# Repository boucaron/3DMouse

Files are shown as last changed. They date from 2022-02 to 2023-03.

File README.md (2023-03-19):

# 3DMouse
## Status
This is still in prototyping phase.... not a polished product by any means, nerd only, but working !
 - Basic Rough Hardware [OK]
 - Firmware [OK]
 - Software for Control and Customization [Control OK, Customization PENDING, Speech Recognition PENDING]

## Overview
Inspired by the great work made by https://github.com/FaqT0tum/Orbion_Space_Mouse
- Using exactly the same hardware but without the LCD Display Part. 
- Cost less than 20$ 
- The idea is to have a small software on the PC where you can "**program**" the firmware of the 3D Mouse according to your software and your preferences, hence the removal of the LCD screen
- Easy to prototype 

## BOM
 - Arduino Pro Micro (**ATMEL32U4**) + Soldered prototyping pins + Associated USB Cable
 - Encoder (**KY-040**)
 - Joystick (**KY-023**)
 - 6 M3 Screw 6mm length
 - Few prototyping female-female cables 

## CAD/3D Printed Parts
- It is a test bed: a base to integrate the Joystick + Arduino, a custom button on top of the Encoder and a custom Encoder/Joystick base.
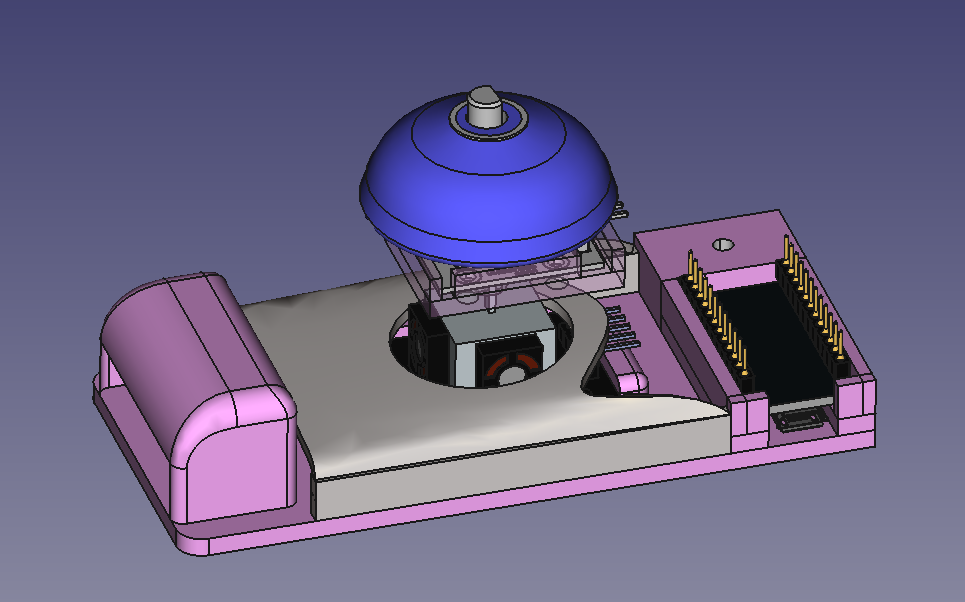
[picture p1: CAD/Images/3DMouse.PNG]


### 3D Printing Steps
- The tolerances for the holes are fully customizable inside the provided FreeCAD files, each printer/filament is different. Try to use the same filament roll when 3D printing those parts to prevent additional iterations due to tolerance changes.

1) Start by first printing the custom Encoder/Joystick base (less than 1 hour in 0.2mm) to setup your baseline for Tolerances for the M3 holes and the **critical tolerance** to the Joystick pin (not too tight, but no play). Orientation is upside down to finish the Joystick pin hole: you will have few supports to remove. Then update accordingly the FreeCAD/STL file for the tolerance.

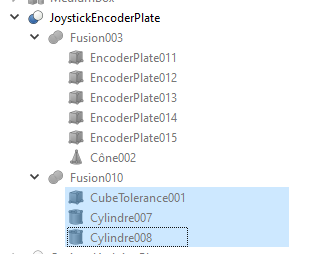
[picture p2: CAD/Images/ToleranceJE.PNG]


2) For the Encoder button you will have to perform the same step for the tolerance (a bit more than 1 hour to print in 0.2mm).

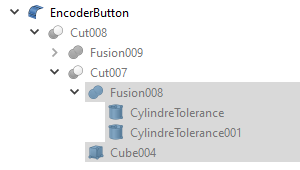
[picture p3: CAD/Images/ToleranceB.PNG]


3) Finally the base using the tolerance for M3 holes you put in the first step.

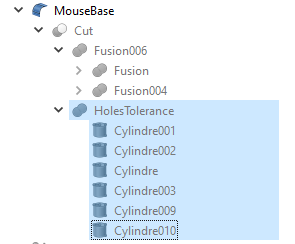
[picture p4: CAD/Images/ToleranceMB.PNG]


## Assembly
1) Put on the 3D Printed Base the Joystick and screw 4 M3 by 6mm on it
2) Put the Encoder on the 3D Printed Joystick/Encoder Plate and screw 2 M3 by 6MM on it
3) Put the 3D Printed Button on the Encoder 
4) Push the 3D Printed Joystick/Encoder Plate on the Joystick pin
5) Put the Arduino in the base as shown in the previous image
6) Put the wires (TODO: schematic)
7) Compile and Upload the firmware

## Firmware 
- Regular Arduino Env using standard libraries + Encoder library (provided in Arduino IDE): compile and upload
- *PoC*: basic features are there, may still change slightly from a commit to another one
- High-Level:
    -   Basic Loop: 
        -  Read Serial Port (if something present to change the configuration/the mode of the mouse)
        -  Read 3D Mouse Inputs (Buttons, Encoder, Joystick)
        -  Process and write to the PC through USB HID (Keyboard/Mouse)
    -   Features:
        - Debug Hardware (serial monitor) [OK]
        -  Basic Mouse Emulator (single button) [OK]
        -  **FreeCAD** (translate, rotation mode) [OK] [Experimental: Click on Joystick Button switch back and forth from Translate/Rotate mode]
        -  **Blender** (translate, rotation mode) [OK]
        -  **ChopChop3D Slicer** (translate, rotation mode) [OK]
        -  **Fusion360** (translate, rotation mode) [OK]	
        -  **3D Builder** (translate, rotation mode) [OK]
        -  **Painter 3D** (translate, rotation mode) [OK]
        -  **OpenSCAD** (translate, rotation mode) [OK]
        -  ZBrush (translate, rotation, scale mode) [TO TEST]
    -   How to:
        -  Connect the 3DMouse to the Computer
        -  Arduino IDE: Compile and Upload the Firmware
        -  Arduino IDE: Launch the Serial Monitor
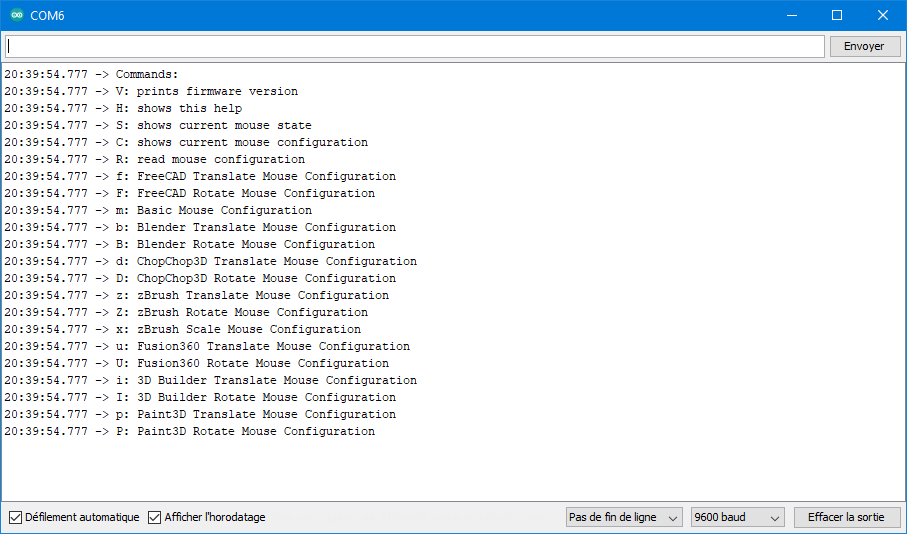
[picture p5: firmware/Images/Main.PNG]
	
        -  Connect with 9600 baud, No End of Line
        -  Type H and Send
        -  Then choose the mode you need: Type the character and Send

## Software
- *PoC*: basic features are there, may change a bit from a commit to another one
    -   Connect to the Mouse [OK]
    -   Serial Port Monitor [OK]
    -   Update the Mode of the Mouse on the Fly with Buttons [OK]
    -   Customization for Mouse Configuration [PENDING] --> Actually there are several modes already implemented, you can easily add yours
    -   Speech Recognition (using Whisper) + Speech Synthesis [WORK IN PROGRESS]
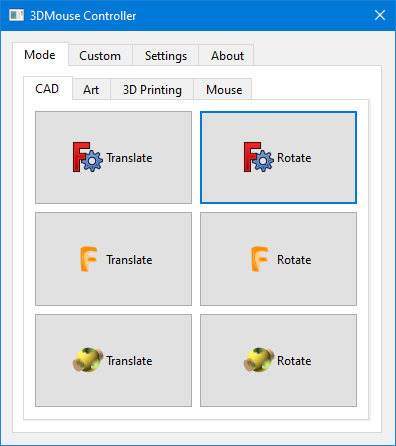
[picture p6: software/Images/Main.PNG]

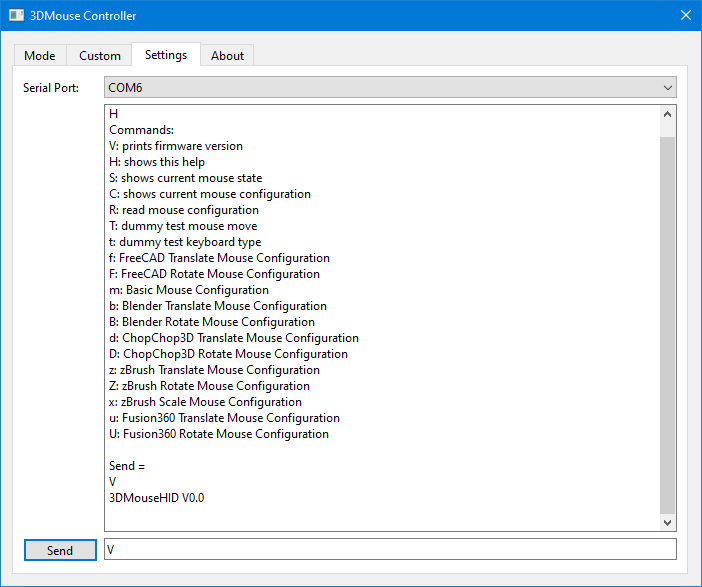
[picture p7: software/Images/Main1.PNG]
	
    
# License
**MIT** see LICENSE file.

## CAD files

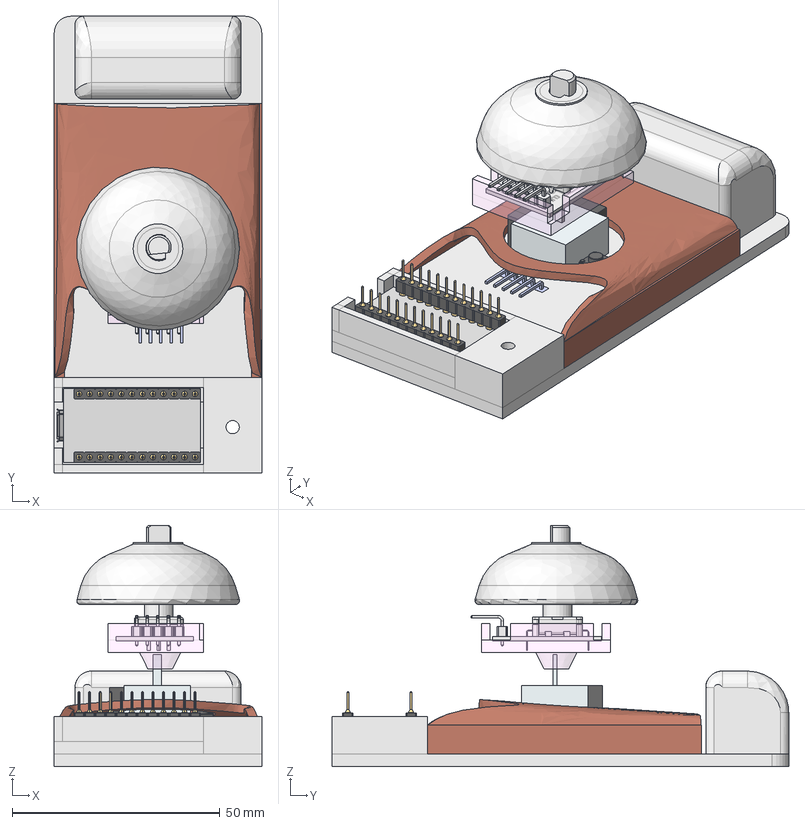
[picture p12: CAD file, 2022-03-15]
CAD/3DMouse_CoverJoystick.FCStd
50.0 x 110.0 x 58.1 mm
Rotary Encoder
Rotary Encoder001
Rotary Encoder002
Rotary Encoder003
D-handle
pcb
2.54 5PIN 90
2.54 5PIN 091
2.54 5PIN 092
2.54 5PIN 093
2.54 5PIN 094
2.54 5PIN 095
2.54 5PIN 096
2.54 5PIN 097
2.54 5PIN 098
2.54 5PIN 099
board001
potentiometer___010
potentiometer___011
potentiometer___012
potentiometer___013
potentiometer___015
potentiometer___016
potentiometer___017
potentiometer___018
tactileswitch-short001
micro board
MICRO_stackable header 12
MICRO_stackable header pin
MICRO_stackable header pin001
MICRO_stackable header pin002
MICRO_stackable header pin003
MICRO_stackable header pin004
MICRO_stackable header pin005
MICRO_stackable header pin006
MICRO_stackable header pin007
MICRO_stackable header pin008
MICRO_stackable header pin009
MICRO_stackable header pin010
MICRO_stackable header pin011
micro usb shell
micro usb internal
micro usb contact
micro usb contact001
micro usb contact002
micro usb contact003
micro usb contact004
atmega32U4
MICRO_cap106C
MICRO_cap106C001
MICRO_stackable header 014
MICRO_stackable header pin012
MICRO_stackable header pin013
MICRO_stackable header pin014
MICRO_stackable header pin015
MICRO_stackable header pin016
MICRO_stackable header pin017
MICRO_stackable header pin018
MICRO_stackable header pin019
MICRO_stackable header pin020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

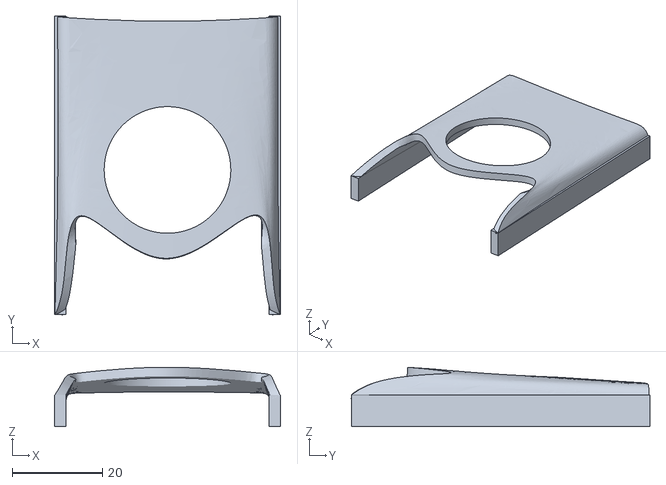
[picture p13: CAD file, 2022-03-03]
STL/CoverJoystick.stl
50.0 x 66.1 x 13.1

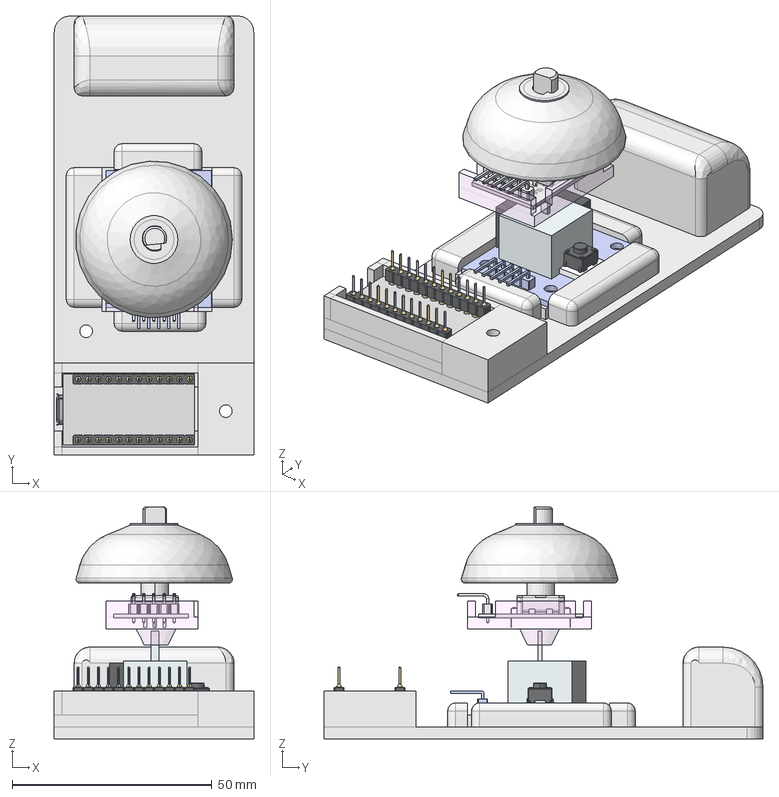
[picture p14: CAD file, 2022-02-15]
CAD/3DMouse.FCStd
50.0 x 110.0 x 58.1 mm
Rotary Encoder
Rotary Encoder001
Rotary Encoder002
Rotary Encoder003
D-handle
pcb
2.54 5PIN 90
2.54 5PIN 091
2.54 5PIN 092
2.54 5PIN 093
2.54 5PIN 094
2.54 5PIN 095
2.54 5PIN 096
2.54 5PIN 097
2.54 5PIN 098
2.54 5PIN 099
board
potentiometer___
potentiometer___001
potentiometer___002
potentiometer___003
potentiometer___005
potentiometer___006
potentiometer___007
potentiometer___008
tactileswitch-short
micro board
MICRO_stackable header 12
MICRO_stackable header pin
MICRO_stackable header pin001
MICRO_stackable header pin002
MICRO_stackable header pin003
MICRO_stackable header pin004
MICRO_stackable header pin005
MICRO_stackable header pin006
MICRO_stackable header pin007
MICRO_stackable header pin008
MICRO_stackable header pin009
MICRO_stackable header pin010
MICRO_stackable header pin011
micro usb shell
micro usb internal
micro usb contact
micro usb contact001
micro usb contact002
micro usb contact003
micro usb contact004
atmega32U4
MICRO_cap106C
MICRO_cap106C001
MICRO_stackable header 014
MICRO_stackable header pin012
MICRO_stackable header pin013
MICRO_stackable header pin014
MICRO_stackable header pin015
MICRO_stackable header pin016
MICRO_stackable header pin017
MICRO_stackable header pin018
MICRO_stackable header pin019
MICRO_stackable header pin020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

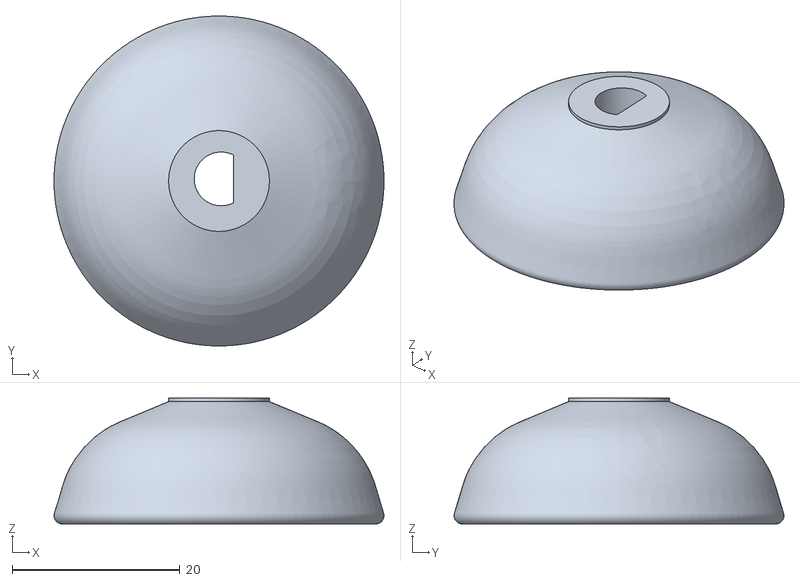
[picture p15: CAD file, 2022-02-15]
STL/EncoderButton.stl
39.3 x 39.3 x 15.0

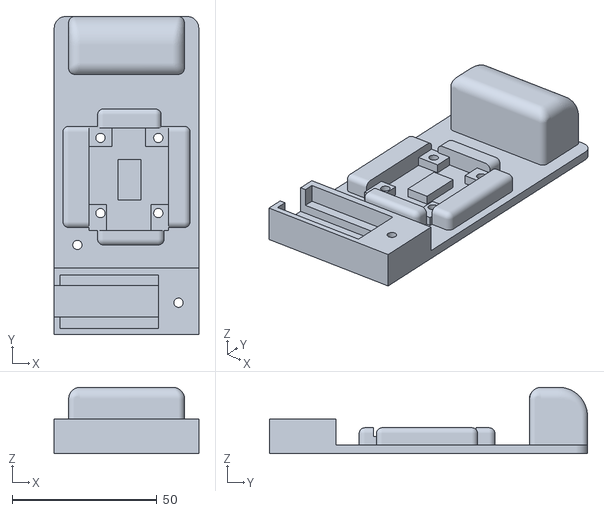
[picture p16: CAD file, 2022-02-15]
STL/MouseBase.stl
50.0 x 110.0 x 23.0

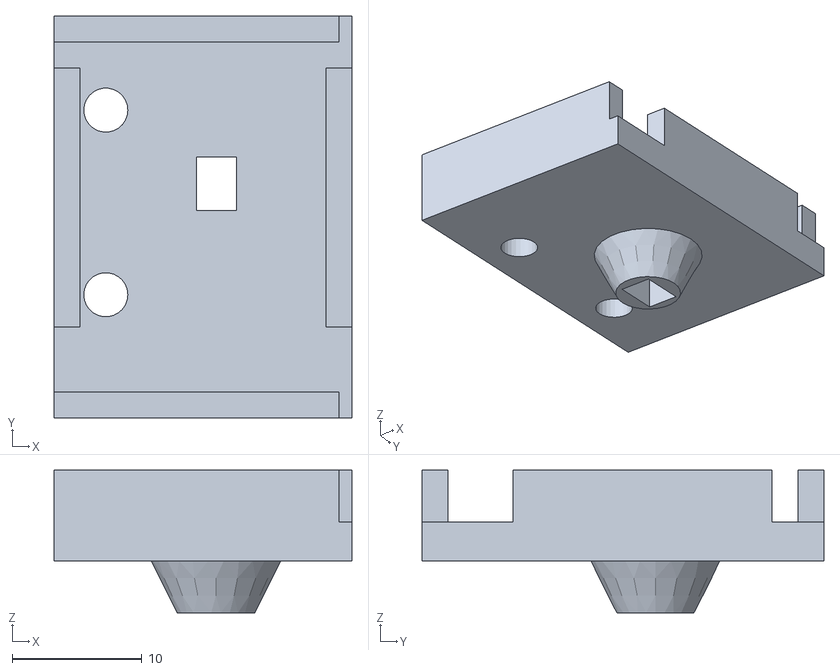
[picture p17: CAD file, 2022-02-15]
STL/JoystickEncodePlate.stl
23.0 x 31.0 x 11.0

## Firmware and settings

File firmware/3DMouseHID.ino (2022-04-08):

// (c) 2022 Julien BOUCARON under MIT License


// Standard Arduino Lib
#include "Keyboard.h"
#include "Mouse.h"

#ifdef JB3DMOUSE_USE_ENCODER
#include "Encoder.h" // https://github.com/PaulStoffregen
#endif

#define SERIALBUFLEN 40
#define MOUSEBUFLEN 20

const char *MVERSION = "3DMouseHID V0.1";

const int pinLed = LED_BUILTIN;

// JOYSTICK
const int horzPin = A1;         // Pin Analog output of X
const int vertPin = A2;        // Pin Analog output of Y
const int joyButt = 15;         // Pin Joystick Button

#ifdef JB3DMOUSE_USE_ENCODER
// ENCODER
const int encBut = 5;    //Pin encoder Button
const int encDT = 7;       // Pin  Detect
const int encCLK = 6;      // Pin  Clockwise
Encoder myEnc(encDT, encCLK);
long positionEnc  = -999;
#endif


void freecadConfiguration(bool);
void basicMouseConfiguration();
void blenderConfiguration(bool);
void chopchop3DConfiguration(bool);
void zBrushConfiguration(int);
void fusion360Configuration(bool);
void M3DBuilderConfiguration(bool);
void Paint3DConfiguration(bool);
void OpenSCADConfiguration(bool);




struct  MouseState {
  byte UpX, DownX;
  byte UpY, DownY;
  byte UpZ, DownZ;
  byte ButtonZ;
  int RotateZ;


  int YZero, XZero;
  int offsetJoyX, offsetJoyY;
  int XValue, YValue;
  int XSens, YSens;

 


  // Move performed before releasing
//   int x,y;

  void reset() {
    UpX = 0 ; DownX = 0;
    UpY = 0 ; DownY = 0;
    UpZ = 0 ; DownZ = 0;
    ButtonZ = 0 ;
    RotateZ = 0;
    XSens = 0; YSens = 0;

   
    offsetJoyX = 5;    // set this value if the joystick moves by itself : 15
    offsetJoyY = 5;    // set this value if the joystick moves by itself : 15


  }

  void setup() {
    reset();
    YZero = 0; XZero = 0;
    YZero = analogRead(vertPin);
    XZero = analogRead(horzPin);
   
 /*   x = 0;
    y = 0; */
  }


  void print() {
    Serial.println(F("State:"));
    Serial.print(F("UpX:")); Serial.print(UpX); Serial.println();
    Serial.print(F("DownX:")); Serial.print(DownX); Serial.println();
    Serial.print(F("UpY:")); Serial.print(UpY); Serial.println();
    Serial.print(F("DownY:")); Serial.print(DownY); Serial.println();
    Serial.print(F("UpZ:")); Serial.print(UpZ); Serial.println();
    Serial.print(F("DownZ:")); Serial.print(DownZ); Serial.println();
    Serial.print(F("ButtonZ:")); Serial.print(ButtonZ); Serial.println();
    Serial.print(F("RotateZ:")); Serial.print(RotateZ); Serial.println();
    Serial.print(F("XZero:")); Serial.print(XZero); Serial.println();
    Serial.print(F("YZero:")); Serial.print(YZero); Serial.println();    
    Serial.print(F("OffsetJoyX")); Serial.print(offsetJoyX); Serial.println();
    Serial.print(F("OffsetJoyY")); Serial.print(offsetJoyY); Serial.println();
    Serial.print(F("XValue:")); Serial.print(XValue); Serial.println();
    Serial.print(F("YValue:")); Serial.print(YValue); Serial.println();
    Serial.print(F("XSens:")); Serial.print(XSens); Serial.println();
    Serial.print(F("YSens:")); Serial.print(YSens); Serial.println();
  }



};



enum MouseKeyHIDMode {
  NOTSET,
  KEYBOARD_PRESS,
  KEYBOARD_RELEASE,
  MOUSE_PRESS,
  MOUSE_RELEASE
};

struct MouseHIDData {
  uint8_t mouseButton;
  int8_t xAxis, yAxis, wheel;
  void (*callback) ();
};

struct KeyHIDData {
  uint8_t keyboardCode;
  void (*callback) ();
};

union HIDData {
  MouseHIDData mouse;
  KeyHIDData keyboard;
};


/** Sent message */
struct MouseKeyHID {
  MouseKeyHIDMode mode;
  HIDData data;
  


  void print() {
    Serial.print("<<");
    switch (mode) {
       case NOTSET: Serial.print(F("NOTSET")); break;
       case KEYBOARD_PRESS: Serial.print(F("KEYBOARD_PRESS")); break;
       case KEYBOARD_RELEASE: Serial.print(F("KEYBOARD_RELEASE")); break;
       case MOUSE_PRESS: Serial.print(F("MOUSE_PRESS")); break;
       case MOUSE_RELEASE: Serial.print(F("MOUSE_RELEASE")); break;
       default: Serial.print(F("Unknown mode!")); break;
    }
    Serial.print(F(":"));
    if ( mode == KEYBOARD_PRESS || mode == KEYBOARD_RELEASE ) {
      Serial.print(data.keyboard.keyboardCode); Serial.print(":");     
    }
    else if ( mode == MOUSE_PRESS || mode == MOUSE_RELEASE ) {
     Serial.print(data.mouse.mouseButton); Serial.print(F(":"));
     Serial.print(data.mouse.xAxis); Serial.print(F(":"));
     Serial.print(data.mouse.yAxis); Serial.print(F(":"));
     Serial.print(data.mouse.wheel);  Serial.print(F(":"));
    }
    Serial.println(F(">>"));
  }

  void read() {
    int mmode = Serial.parseInt();
    switch ( mmode ) {
      case 0: mode = NOTSET; break;
      case 1: mode = KEYBOARD_PRESS; break;
      case 2: mode = KEYBOARD_RELEASE; break;
      case 3: mode = MOUSE_PRESS; break;
      case 4: mode = MOUSE_RELEASE; break;
      default: Serial.print(F("Unknown mode!")); break;
  }
    if ( mode == KEYBOARD_PRESS || mode == KEYBOARD_RELEASE ) {
      data.keyboard.keyboardCode = Serial.parseInt();
    } else if ( mode == MOUSE_PRESS || mode == MOUSE_RELEASE ) {
      data.mouse.mouseButton = Serial.parseInt();
      data.mouse.xAxis = Serial.parseInt();
      data.mouse.yAxis = Serial.parseInt();
      data.mouse.wheel = Serial.parseInt();
    }    
  }

  void writeHID(byte up, int XSens, int YSens, MouseState &mouseState) {
    
    if ( up != 0 ) {
      switch ( mode ) {       
        case KEYBOARD_PRESS:
          Keyboard.press(data.keyboard.keyboardCode); 
              // DEBUG
             // Serial.println("Keyboard press");   
             if ( data.keyboard.callback != NULL ) { data.keyboard.callback(); }
          break;
        case KEYBOARD_RELEASE:
          Keyboard.release(data.keyboard.keyboardCode); 
          // DEBUG
          // Serial.println("Keyboard release");
          if ( data.keyboard.callback != NULL ) { data.keyboard.callback(); }   
          break;
        case MOUSE_PRESS: 
          if ( data.mouse.mouseButton != 0 ) {
              Mouse.press(data.mouse.mouseButton);  
              // DEBUG
              // Serial.println("Mouse press");            
          }                
          Mouse.move(data.mouse.xAxis * XSens, data.mouse.yAxis * YSens, data.mouse.wheel);
           
          // DEBUG
          //Serial.print("Mouse move = X  "); Serial.println(data.mouse.xAxis * XSens);
          // Serial.print("Mouse move = Y  "); Serial.println(data.mouse.yAxis * YSens);
          // mouseState.x += data.mouse.xAxis * XSens;
          // mouseState.y += data.mouse.yAxis * YSens;
          // Serial.println( mouseState.x);

          if ( data.mouse.callback != NULL ) { data.mouse.callback(); }
          break;
        case MOUSE_RELEASE:
          if ( data.mouse.mouseButton != 0 ) {
            Mouse.release(data.mouse.mouseButton);
            // DEBUG
            // Serial.println("Mouse release");     
          }          
          Mouse.move(data.mouse.xAxis * XSens, data.mouse.yAxis * YSens, data.mouse.wheel);                   
          // DEBUG
          // Serial.println("Mouse move = X "); Serial.print(data.mouse.xAxis * XSens);
          // Serial.println("Mouse move = Y  "); Serial.print(data.mouse.yAxis * YSens);
          // mouseState.x += data.mouse.xAxis * XSens;
          // mouseState.y += data.mouse.yAxis * YSens;
          if ( data.mouse.callback != NULL ) { data.mouse.callback(); }
          break;
      }
     
    }
  }

  void reset() {
    mode = NOTSET;
  }

  void cleanData() {
    switch(mode) {
      case KEYBOARD_PRESS:                  
      case KEYBOARD_RELEASE:       
          data.keyboard.keyboardCode = 0;
          data.keyboard.callback = NULL;
         break;
      case MOUSE_PRESS:  
      case MOUSE_RELEASE:
          data.mouse.mouseButton = 0;
          data.mouse.xAxis = 0;
          data.mouse.yAxis = 0;
          data.mouse.wheel = 0;
          data.mouse.callback = NULL;
         break;
    }
  }



};



// STATIC BUFFER CONTAININGALL THE CONF
MouseKeyHID mouseBuf[MOUSEBUFLEN];

/**
 * List of moves to be performed on each "key" in sequence
 */
struct MouseKeyConf { 
  int from; // Index in mouseBuf for the move
  int to; // Index in mouseBuf for the move
  
  void reset() { 
    from = -1;
    to  = -1;
  }

  void print() {
    Serial.println(to-from); Serial.println(" moves");
    for(int i = from ; i < to ; i++ ) {      
      mouseBuf[i].print();
    }
  }

  void read() {
    from = Serial.parseInt();
    to = Serial.parseInt();
    for(int i = from ; i < to ; i++ ) {
      mouseBuf[i].read();
    }
  }

  void writeHID(byte up, int XSens, int YSens, MouseState &mouseState) {
    if ( from == -1 || to == -1 ) {
      return;
    } else {
      for(int i = from ; i < to ; i++ ) {
        mouseBuf[i].writeHID(up, XSens, YSens, mouseState);
      }
    }
  }
};


struct MouseConf {
  MouseKeyConf UpX, DownX;
  MouseKeyConf UpY, DownY;
  MouseKeyConf UpZ, DownZ;

  MouseKeyConf ButtonZ;
  MouseKeyConf RotateZ;

// Run before and after performing any "moves"
  MouseKeyConf before, after;

  void reset() {
    UpX.reset(); DownX.reset();
    UpY.reset(); DownY.reset();
    UpZ.reset(); DownZ.reset();

    ButtonZ.reset();
    RotateZ.reset();

  }

  void print() {
    Serial.println(F("Configuration:"));
    Serial.print(F("UpX:")); UpX.print();  Serial.println();
    Serial.print(F("DownX:")); DownX.print(); Serial.println();
    Serial.print(F("UpY:")); UpY.print();  Serial.println();
    Serial.print(F("DownY:")); DownY.print(); Serial.println();
    Serial.print(F("UpZ:")); UpZ.print(); Serial.println();
    Serial.print(F("DownZ:")); DownZ.print(); Serial.println();
    Serial.print(F("ButtonZ:")); ButtonZ.print(); Serial.println();
    Serial.print(F("RotateZ:")); RotateZ.print(); Serial.println();
    Serial.print(F("before:")); before.print(); Serial.println();
    Serial.print(F("after:")); after.print(); Serial.println();
  }

  void read() {
    UpX.read(); DownX.read();
    UpY.read(); DownY.read();
    UpZ.read(); DownZ.read();
    ButtonZ.read(); RotateZ.read();    
    before.read(); after.read();
  } 
  

  void checkAndReleaseMouseButtons(MouseState &state, const MouseState &previousState) {
    if ( state.UpX == 0 && state.UpY == 0 && state.UpZ == 0 && 
         state.DownX == 0 && state.DownY == 0 && state.DownZ == 0 && 
         state.ButtonZ == 0 && state.RotateZ == 0 ) { 
          if ( previousState.UpX != 0 || previousState.UpY != 0 || previousState.UpZ != 0 || 
                previousState.DownX != 0 || previousState.DownY != 0 || previousState.DownZ != 0 || 
                previousState.ButtonZ != 0 || previousState.RotateZ !=  0 ) {         
            Mouse.release(MOUSE_LEFT|MOUSE_MIDDLE|MOUSE_RIGHT);
            // DEBUG
            // Serial.println("Mouse release button = ");
            // DEBOUNCE TEST: HELP FOR FREECAD
            // delay(100);
            
            // Serial.println(mouseButton);    
          
            // DEBUG
            // Serial.println("checkAndReleaseMouseButton X = "); // Serial.println(state.x);
            //Serial.println("Y = "); Serial.println(state.y);
            //state.x = 0;
            // state.y = 0;                    
          }      
         }     
  }
  
  void checkAndReleaseKeyboard(MouseState &state, const MouseState &previousState) {
    if ( state.UpX == 0 && state.UpY == 0 && state.UpZ == 0 && 
         state.DownX == 0 && state.DownY == 0 && state.DownZ == 0 && 
         state.ButtonZ == 0 && state.RotateZ == 0 ) { 
          if ( previousState.UpX != 0 || previousState.UpY != 0 || previousState.UpZ != 0 || 
                previousState.DownX != 0 || previousState.DownY != 0 || previousState.DownZ != 0 || 
                previousState.ButtonZ != 0 || previousState.RotateZ !=  0 ) {                                  
            Keyboard.releaseAll();    
            // DEBUG
            // Serial.println("checkAndReleaseKeyboard Keyboard.releaseAll()");
       
            }      
         }    
  } 

  bool atLeastAMove(const MouseState &state ) {
    if ( state.UpX != 0 || state.UpY != 0 || state.UpZ != 0 ||
        state.DownX != 0 || state.DownZ != 0 || state.DownY != 0 ||
        state.ButtonZ != 0 || state.RotateZ != 0 ) {
      return true;
    }
    return false;
  }

  bool atLeastAButtonPressed(const MouseState &state) {
    if ( state.ButtonZ != 0 ) {
       return true;
    }
    return false;
  }

  void writeHID(MouseState &state, MouseState &previousState) {    

    if ( atLeastAMove(state) ) {
      before.writeHID(1, state.XSens, state.YSens, state);
   
    
      UpX.writeHID(state.UpX, state.XSens, state.YSens, state); 
      DownX.writeHID(state.DownX, state.XSens, state.YSens, state);
      UpY.writeHID(state.UpY, state.XSens, state.YSens, state);
      DownY.writeHID(state.DownY, state.XSens, state.YSens, state);
      UpZ.writeHID(state.UpZ, state.XSens, state.YSens, state); 
      DownZ.writeHID(state.DownZ, state.XSens, state.YSens, state);

      
      ButtonZ.writeHID(state.ButtonZ, state.XSens, state.YSens, state);
      RotateZ.writeHID(state.RotateZ, state.XSens, state.YSens, state);

    
      after.writeHID(1, state.XSens, state.YSens, state);
   
     // Debounce
      if ( atLeastAButtonPressed(state) ) {
         delay(100);
      }

      //  3 Stages delay, small sensitivity very slow and faster    
      bool taken = false;
      if ( state.XSens > 6 || state.YSens > 6   ) {
        if ( !taken && (state.UpX != 0 || state.DownX != 0 || state.UpY != 0 || state.DownY != 0) ) {
          delay(3); 
          taken = true;   
        }
      } 
      if (  (state.XSens > 3 && state.XSens <= 6 ) || (state.YSens > 3 && state.YSens <= 6)  ) {
        if ( !taken && (state.UpX != 0 || state.DownX != 0 || state.UpY != 0 || state.DownY != 0) ) {
          delay(5); 
          taken = true;      
        }
      } 
      if ( (state.XSens >= 1 && state.XSens <= 3) || (state.YSens <= 3 && state.YSens >= 1)  ) {
        if (  !taken && (state.UpX != 0 || state.DownX != 0 || state.UpY != 0 || state.DownY != 0 )) {
          delay(10); // Basic Mouse        
          taken = true;
       }
      } 
    
    }
    else {
      checkAndReleaseMouseButtons(state, previousState);
      checkAndReleaseKeyboard(state, previousState);
    }

    previousState = state;
    
    
  }
};

MouseState mouseState, previousMouseState;
MouseConf mouseConf;

void setup() {
  pinMode(pinLed, OUTPUT);
  pinMode(joyButt, INPUT_PULLUP);
  pinMode(horzPin, INPUT_PULLUP);
  pinMode(vertPin, INPUT_PULLUP);

#ifdef JB3DMOUSE_USE_ENCODER  
  pinMode(encBut, INPUT_PULLUP);
  pinMode(encDT, INPUT);
  pinMode(encCLK, INPUT);
#endif  

  mouseState.setup();
  previousMouseState.setup();
  mouseConf.reset();
  
  Serial.begin(9600);
  Serial.println(MVERSION);
  Mouse.begin();  
  Keyboard.begin();
 
}

void helpCommand() {
  Serial.println(F("Commands:"));
  Serial.println(F("V: prints firmware version"));
  Serial.println(F("H: shows this help"));
  Serial.println(F("S: shows current mouse state"));
  Serial.println(F("C: shows current mouse configuration"));
  Serial.println(F("R: read mouse configuration"));
  Serial.println(F("f: FreeCAD Translate Mouse Configuration"));
  Serial.println(F("F: FreeCAD Rotate Mouse Configuration"));
  Serial.println(F("m: Basic Mouse Configuration"));
  Serial.println(F("b: Blender Translate Mouse Configuration"));
  Serial.println(F("B: Blender Rotate Mouse Configuration"));
  Serial.println(F("d: ChopChop3D Translate Mouse Configuration"));
  Serial.println(F("D: ChopChop3D Rotate Mouse Configuration"));
  Serial.println(F("z: zBrush Translate Mouse Configuration"));
  Serial.println(F("Z: zBrush Rotate Mouse Configuration"));
  Serial.println(F("x: zBrush Scale Mouse Configuration"));
  Serial.println(F("u: Fusion360 Translate Mouse Configuration"));
  Serial.println(F("U: Fusion360 Rotate Mouse Configuration"));
  Serial.println(F("i: 3D Builder Translate Mouse Configuration"));
  Serial.println(F("I: 3D Builder Rotate Mouse Configuration")); 
  Serial.println(F("p: Paint3D Translate Mouse Configuration"));
  Serial.println(F("P: Paint3D Rotate Mouse Configuration"));
  Serial.println(F("o: OpenSCAD Translate Mouse Configuration"));
  Serial.println(F("O: OpenSCAD Rotate Mouse Configuration"));
}

void readSerialPort() {
  static char message[SERIALBUFLEN];
  static unsigned int message_pos = 0;

  // Check if any configuration change
  while (Serial.available() > 0) {
    //Read the next available byte in the serial receive buffer
    char inByte = Serial.read();
    switch (inByte) {
      case 'V':
        Serial.println(MVERSION);
        break;
      case 'H':
        helpCommand();
        break;
      case 'S':
        mouseState.print();
        break;
      case 'C':
        mouseConf.print();
        break;
      case 'R':
        mouseConf.read();
        break;     
      case 'f': // Translate
        Serial.println(F("FreeCAD Translate Mode"));
        freecadConfiguration(false);
        break;
      case 'F': // Rotate
        Serial.println(F("FreeCAD Rotate Mode"));
        freecadConfiguration(true);
        break;
      case 'm':
        Serial.println(F("Basic Mouse Mode"));
        basicMouseConfiguration();
        break; 
      case 'b':
        Serial.println(F("Blender Translate Mode"));
        blenderConfiguration(false);
        break;
      case 'B':
        Serial.println(F("Blender Rotate Mode"));
        blenderConfiguration(true);
        break; 
      case 'd':
        Serial.println(F("ChopChop3D Translate Mode"));
        chopchop3DConfiguration(false);
        break;
      case 'D':
        Serial.println(F("ChopChop3D Rotate Mode"));
        chopchop3DConfiguration(true);
        break;      
      case 'z':
        Serial.println(F("zBrush Translate Mode"));
        zBrushConfiguration(0);
        break; 
      case 'Z':
        Serial.println(F("zBrush Rotate Mode"));
        zBrushConfiguration(2);
        break;  
       case 'x':
        Serial.println(F("zBrush Scale Mode"));
        zBrushConfiguration(1);
        break;     
      case 'u':
        Serial.println(F("Fusion360 Translate Mode"));
        fusion360Configuration(false);
        break;
      case 'U':
        Serial.println(F("Fusion360 Rotate Mode"));
        fusion360Configuration(true);
        break;
      case 'i':
        Serial.println(F("3D Builder Translate Mode"));
        M3DBuilderConfiguration(false);
        break;
      case 'I':
        Serial.println(F("3D Builder Rotate Mode"));
        M3DBuilderConfiguration(true);
        break;
      case 'p':
        Serial.println(F("Paint 3D Translate Mode"));
        Paint3DConfiguration(false);
        break;
      case 'P':
        Serial.println(F("Paint 3D Rotate Mode"));
        Paint3DConfiguration(true);
        break;
       case 'o':
        Serial.println(F("OpenSCAD Translate Mode"));
        OpenSCADConfiguration(false);
        break;
      case 'O':
        Serial.println(F("OpenSCAD Rotate Mode"));
        OpenSCADConfiguration(true);
        break;        
      default:
        Serial.print(F("Unknown command:"));
        Serial.print(inByte);
        helpCommand();
    }
  }
  // Update configuration
}




void readMouse() {
  // Check if any change
  mouseState.reset();

  // Update for writeKeyboard
  mouseState.YValue = analogRead(vertPin);
  mouseState.XValue = analogRead(horzPin);

  const int myDiv = 100;

  if ( mouseState.YValue -  mouseState.YZero < -mouseState.offsetJoyY ) {
    mouseState.UpY = 1; mouseState.DownY = 0;    
    mouseState.YSens = (mouseState.YZero - mouseState.YValue) / myDiv;
    if ( mouseState.YSens == 0 ) {
      mouseState.UpY = 0;
    }
  }
  if (mouseState.YValue - mouseState.YZero > mouseState.offsetJoyY ) {
    mouseState.UpY = 0; mouseState.DownY = 1;
    mouseState.YSens = (mouseState.YValue -  mouseState.YZero) / myDiv;
    if ( mouseState.YSens == 0 ) {
      mouseState.DownY = 0;
    }
  }
  if ( mouseState.XValue -  mouseState.XZero < -mouseState.offsetJoyX ) {
    mouseState.UpX = 1; mouseState.DownX = 0;    
    mouseState.XSens = (mouseState.XZero - mouseState.XValue) / myDiv;
    if ( mouseState.XSens == 0 ) {
      mouseState.UpX = 0;
    }
  }
  if ( mouseState.XValue -  mouseState.XZero > mouseState.offsetJoyX ) {
    mouseState.UpX = 0; mouseState.DownX = 1;
    mouseState.XSens = (mouseState.XValue -  mouseState.XZero) / myDiv;
     if ( mouseState.XSens == 0 ) {
      mouseState.DownX = 0;
    }
  }
  if (digitalRead(joyButt) == HIGH) {
    mouseState.ButtonZ = 0;
  } else {
    mouseState.ButtonZ = 1;
  }

#ifdef JB3DMOUSE_USE_ENCODER
  //Encoder
  long newEPosition = myEnc.read();
  if (newEPosition != positionEnc) {
    bool encoderLeft = false;
    if ( positionEnc - newEPosition > 0 ) {
      encoderLeft = true;
      mouseState.UpZ = 1;
      mouseState.DownZ = 0;
    } else {
      mouseState.UpZ = 0;
      mouseState.DownZ = 1;
    }
    positionEnc = newEPosition;

  }
  if (digitalRead(encBut) == LOW) {
    // mouseState.ButtonZ = 0;
  } else {
    // mouseState.ButtonZ = 1;
  }
#endif



}

void writeHID() {
  mouseConf.writeHID(mouseState, previousMouseState);
}





void freecadSwitchMode() {
  Serial.println("freecadSwitchMode");
  Mouse.release(MOUSE_LEFT|MOUSE_MIDDLE|MOUSE_RIGHT);
  delay(250);
  if ( mouseBuf[0].data.mouse.mouseButton == MOUSE_MIDDLE ) {   
    freecadConfiguration(true);
  } else {
    freecadConfiguration(false);
  }
 
}
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
void loop() {
  readSerialPort();
  readMouse();
  writeHID();
}

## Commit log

2022-02-15 Add Basic CAD
    [3DMouse.FCStd]
2022-02-15 Add STLs
    [EncoderButton.stl, JoystickEncodePlate.stl, MouseBase.stl]
2022-02-15 Add assembly steps
2022-02-16 Quick fix mouse hold/release button
    [3DMouseHID.ino]
2022-02-16 Add generalization to mouse release buttons
    Add basic FreeCAD Translation mode
2022-02-20 Connect Buttons
    Serial Port Scan
2022-02-20 Add send button
2022-02-28 Small refactoring -> add state in writeHID callstack
    Removed mouse and keyboard test
    Update sensitivity stage -> 3 steps easier to use
2022-03-03 Small refactoring
    + Glitch robustness for FreeCAD mainly (mouse release with no position
    move on X,Y)
    [3DMouseHID.ino]
2022-03-03 Add variant with cover
    [3DMouse_CoverJoystick.FCStd]
2022-03-03 Add variant with small cover
    [CoverJoystick.stl]
2022-03-03 Minor orientation change
    [3DMouse_CoverJoystick.FCStd]
2022-03-03 CAD Update
2022-03-03 Experiment
    with callbacks in FreeCAD switch from/to Translate/Rotate
    with Button
2022-03-03 Bug fix Button Switch Mode Translate/Rotate for FreeCAD
    [3DMouseHID.ino]
2022-03-15 3DBuilder Mode
    Dynamic Memory Optimization for Serial.print
    [3DMouse_CoverJoystick.FCStd]
